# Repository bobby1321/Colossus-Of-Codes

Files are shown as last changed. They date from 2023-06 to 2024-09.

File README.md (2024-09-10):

# Colossus of Codes QMK Keyboard
This keyboard is a custom QMK-enabled board with a few unique features:
- Left-hand numpad
- Extra row of remappable function keys (F13-F24 by default)
- Rotary Encoder (Volume control by default)
- IO Expander chips to allow for 121 keys with a single RP2040!

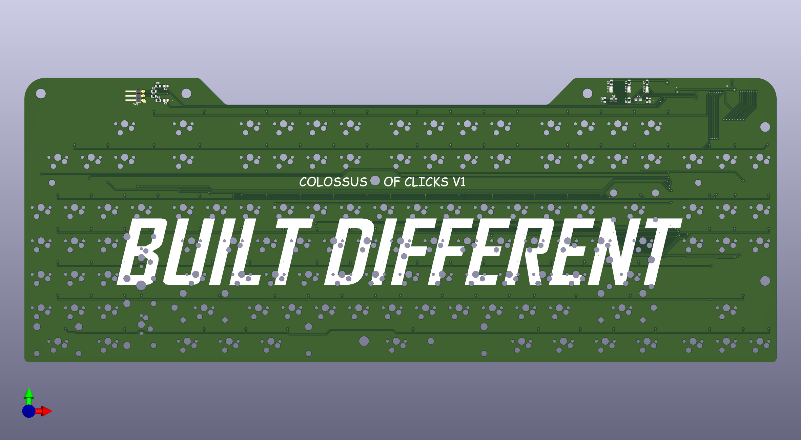
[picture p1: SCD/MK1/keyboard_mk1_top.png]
position


This design still needs some work (hence the V2 TODO list), but it is functional, and I've been using it as my daily driver for a few months now (as of Sept '24).

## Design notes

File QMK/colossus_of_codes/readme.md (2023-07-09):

# colossus_of_codes

colossus_of_codes

*A short description of the keyboard/project*

* Keyboard Maintainer: [bobby1321](https://github.com/bobby1321)
* Hardware Supported: *The PCBs, controllers supported*
* Hardware Availability: *Links to where you can find this hardware*

Make example for this keyboard (after setting up your build environment):

    make colossus_of_codes:default

Flashing example for this keyboard:

    make colossus_of_codes:default:flash

See the [build environment setup](https://docs.qmk.fm/#/getting_started_build_tools) and the [make instructions](https://docs.qmk.fm/#/getting_started_make_guide) for more information. Brand new to QMK? Start with our [Complete Newbs Guide](https://docs.qmk.fm/#/newbs).

## Bootloader

Enter the bootloader in 3 ways:

* **Bootmagic reset**: Hold down the key at (0,0) in the matrix (usually the top left key or Escape) and plug in the keyboard
* **Physical reset button**: Briefly press the button on the back of the PCB - some may have pads you must short instead
* **Keycode in layout**: Press the key mapped to `QK_BOOT` if it is available

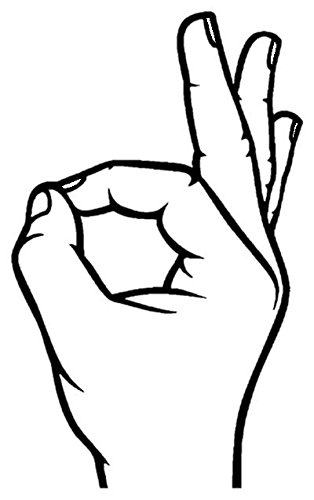
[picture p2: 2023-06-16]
Images/41HmWfeYpDL.jpg

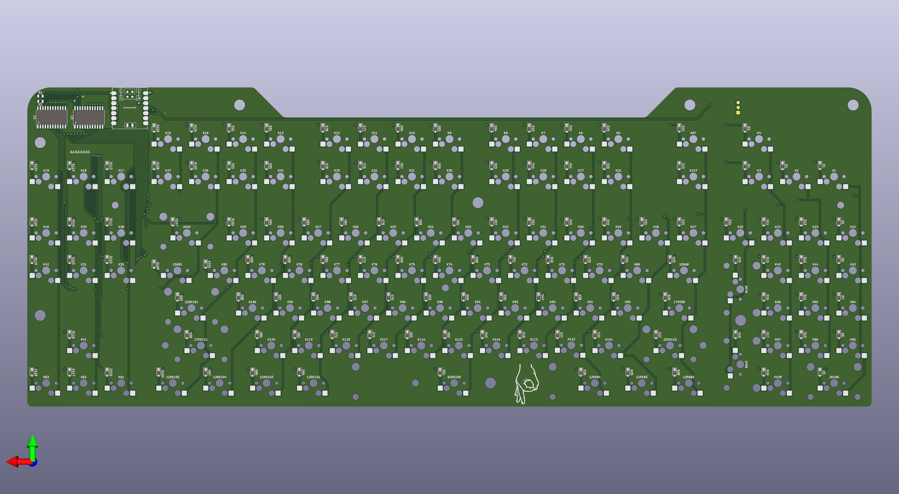
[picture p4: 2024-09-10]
SCD/MK1/keyboard_mk1_bottom.png

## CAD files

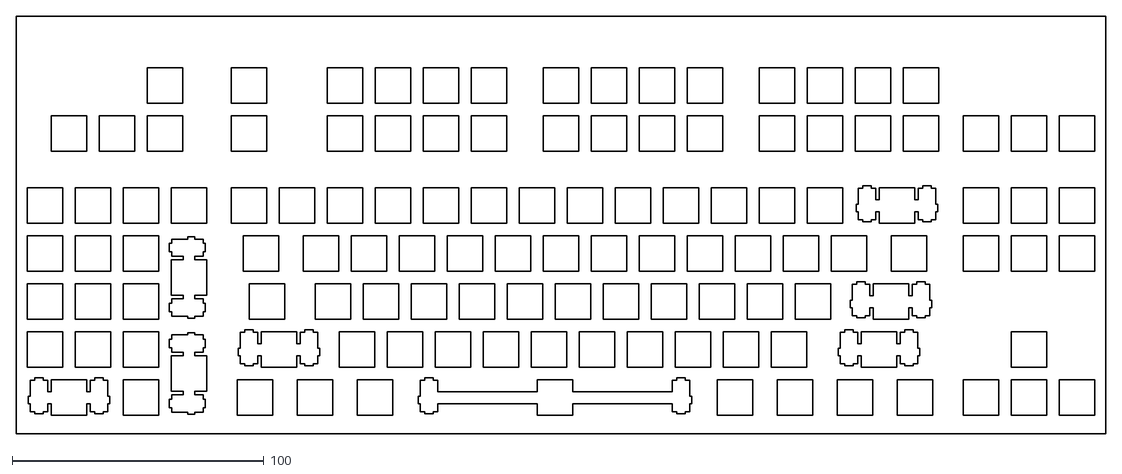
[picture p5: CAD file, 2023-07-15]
CAD/b24a91eeafafb1037e10217dc15ee6c39c0a37f9_switch.dxf
432.5 x 165.6

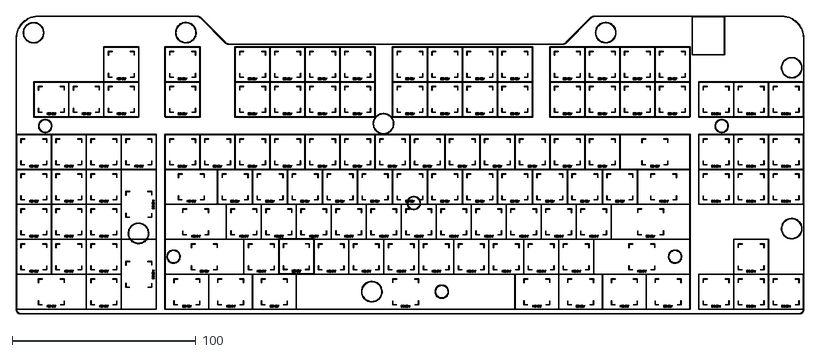
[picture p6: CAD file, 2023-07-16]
SCD/MK1/Gerbers/keyboard_mk1-User_Drawings.dxf
428.8 x 162.0

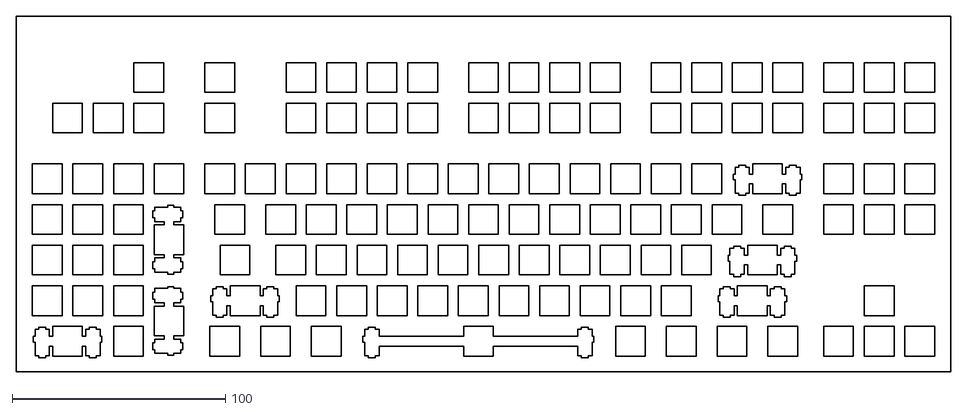
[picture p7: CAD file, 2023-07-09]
top_plate_drawing.dxf
438.6 x 166.9

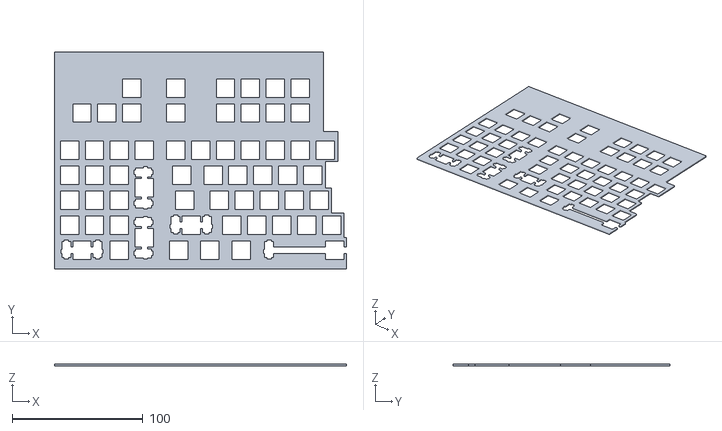
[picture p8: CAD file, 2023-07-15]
CAD/top_plate_left.stl
222.9 x 165.6 x 1.50

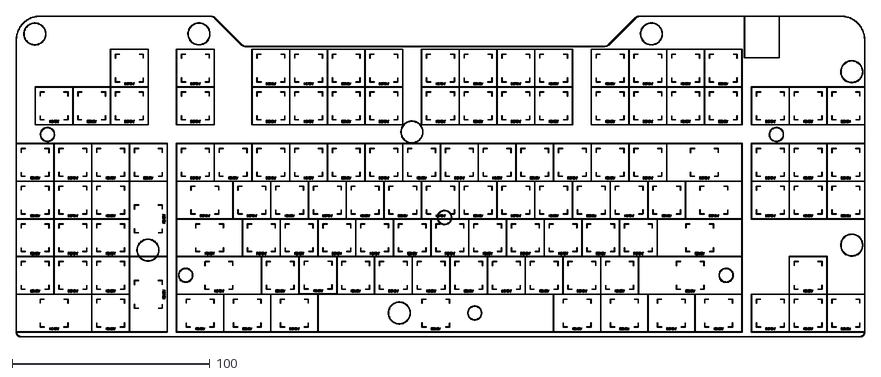
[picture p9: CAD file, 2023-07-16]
SCD/MK1/Gerbers/keyboard_mk1-User_Comments.dxf
428.8 x 162.0

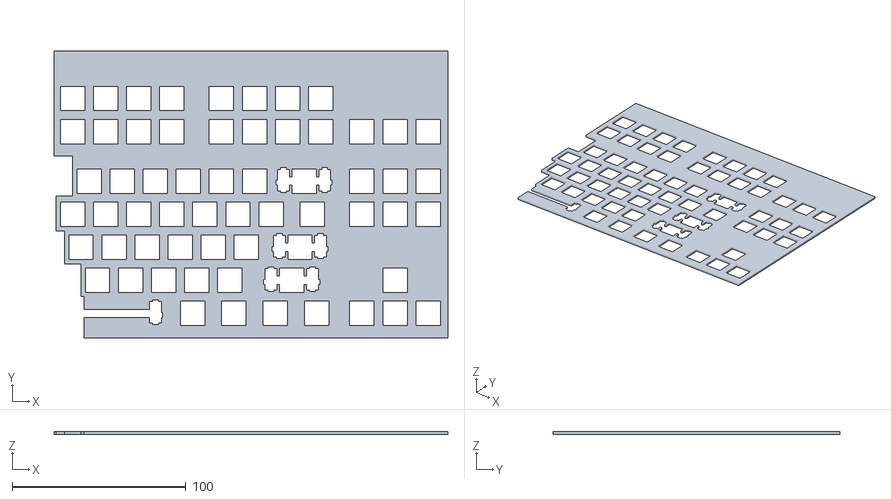
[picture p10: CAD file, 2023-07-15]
CAD/top_plate_right.stl
227.0 x 165.6 x 1.50

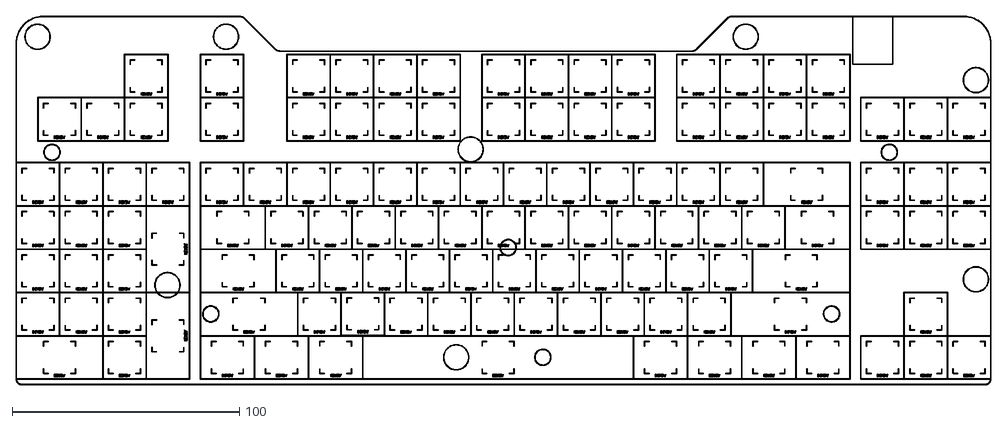
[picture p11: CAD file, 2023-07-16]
SCD/MK1/Gerbers/keyboard_mk1-Edge_Cuts.dxf
428.8 x 162.0

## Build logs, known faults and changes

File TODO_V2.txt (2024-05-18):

Things to do in V2:
	- Try to reduce dead area on board (talking about you top left corner)
	- Bigger resistors on LEDs (they are too bright)
	- Silkscreen things
	- Maybe design the case before / at the same time as the board so holes don't end up under keys :)
	- Also just put more holes in general
	- Try to put the chips on the front?
	- Maybe get chips with pull-down inputs, or just add pull-down resistors since I already have extra chips...
	- MEGA GAM3R RGB (per key, or just backlight?)
	- Thermal relief thingys? Make them better so that it doens't suck soldering to the ground plane.
	- Make the top 2 rows angled cause that would be cool
	- Toggle switches?
	- OLED screen...? maybe that's excessive...
	- Layer indicator LEDs
	- Increase kerf (that's a thing, right?) on top plate DXF
	- Also apparently construction lines get transfered to DXFs :)
	- Move function keys/esc closer to the number row
	- Move lock lights so that they are actually visible
	- Figure out how to support the volume roller better
	- Use thinner stainless steel
	- Print bottom plates stronger

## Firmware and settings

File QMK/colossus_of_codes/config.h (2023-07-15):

// Copyright 2023 bobby1321 (@bobby1321)
// SPDX-License-Identifier: GPL-2.0-or-later

#pragma once

/*
 * Feature disable options
 *  These options are also useful to firmware size reduction.
 */

/* disable debug print */
//#define NO_DEBUG

/* disable print */
//#define NO_PRINT

/* disable action features */
//#define NO_ACTION_LAYER
//#define NO_ACTION_TAPPING
//#define NO_ACTION_ONESHOT

#define I2C_DRIVER I2CD1
#define I2C1_SDA_PIN GP6
#define I2C1_SCL_PIN GP7

#define MATRIX_ROWS 7
#define MATRIX_COLS 22

#define ENCODERS_PAD_A { GP3 } // these are reveresed to reverse the direction of the encoder
#define ENCODERS_PAD_B { GP4 }

#define ENCODER_RESOLUTION 2

//#define DEBUG_MATRIX_SCAN_RATE

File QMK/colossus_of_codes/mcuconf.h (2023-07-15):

/*
    ChibiOS - Copyright (C) 2006..2021 Giovanni Di Sirio

    Licensed under the Apache License, Version 2.0 (the "License");
    you may not use this file except in compliance with the License.
    You may obtain a copy of the License at

        http://www.apache.org/licenses/LICENSE-2.0

    Unless required by applicable law or agreed to in writing, software
    distributed under the License is distributed on an "AS IS" BASIS,
    WITHOUT WARRANTIES OR CONDITIONS OF ANY KIND, either express or implied.
    See the License for the specific language governing permissions and
    limitations under the License.
*/

#ifndef MCUCONF_H
#define MCUCONF_H

/*
 * RP2040_MCUCONF drivers configuration.
 *
 * IRQ priorities:
 * 3...0        Lowest...Highest.
 *
 * DMA priorities:
 * 0...1        Lowest...Highest.
 */

#define RP2040_MCUCONF

/*
 * HAL driver system settings.
 */
#define RP_NO_INIT                          FALSE
#define RP_CORE1_START                      FALSE
#define RP_CORE1_VECTORS_TABLE              _vectors
#define RP_CORE1_ENTRY_POINT                _crt0_c1_entry
#define RP_CORE1_STACK_END                  __c1_main_stack_end__

/*
 * IRQ system settings.
 */
#define RP_IRQ_SYSTICK_PRIORITY             2
#define RP_IRQ_TIMER_ALARM0_PRIORITY        2
#define RP_IRQ_TIMER_ALARM1_PRIORITY        2
#define RP_IRQ_TIMER_ALARM2_PRIORITY        2
#define RP_IRQ_TIMER_ALARM3_PRIORITY        2
#define RP_IRQ_ADC1_PRIORITY                3
#define RP_IRQ_UART0_PRIORITY               3
#define RP_IRQ_UART1_PRIORITY               3
#define RP_IRQ_SPI0_PRIORITY                2
#define RP_IRQ_SPI1_PRIORITY                2
#define RP_IRQ_USB0_PRIORITY                3
#define RP_IRQ_I2C0_PRIORITY                2
#define RP_IRQ_I2C1_PRIORITY                1

/*
 * ADC driver system settings.
 */
#define RP_ADC_USE_ADC1                     TRUE

/*
 * SIO driver system settings.
 */
#define RP_SIO_USE_UART0                    TRUE
#define RP_SIO_USE_UART1                    FALSE

/*
 * SPI driver system settings.
 */
#define RP_SPI_USE_SPI0                     TRUE
#define RP_SPI_USE_SPI1                     FALSE
#define RP_SPI_SPI0_RX_DMA_CHANNEL          RP_DMA_CHANNEL_ID_ANY
#define RP_SPI_SPI0_TX_DMA_CHANNEL          RP_DMA_CHANNEL_ID_ANY
#define RP_SPI_SPI1_RX_DMA_CHANNEL          RP_DMA_CHANNEL_ID_ANY
#define RP_SPI_SPI1_TX_DMA_CHANNEL          RP_DMA_CHANNEL_ID_ANY
#define RP_SPI_SPI0_DMA_PRIORITY            1
#define RP_SPI_SPI1_DMA_PRIORITY            1
#define RP_SPI_DMA_ERROR_HOOK(spip)

/*
 * PWM driver system settings.
 */
#define RP_PWM_USE_PWM0                     FALSE
#define RP_PWM_USE_PWM1                     FALSE
#define RP_PWM_USE_PWM2                     FALSE
#define RP_PWM_USE_PWM3                     FALSE
#define RP_PWM_USE_PWM4                     FALSE
#define RP_PWM_USE_PWM5                     FALSE
#define RP_PWM_USE_PWM6                     FALSE
#define RP_PWM_USE_PWM7                     FALSE
#define RP_PWM_IRQ_WRAP_NUMBER_PRIORITY     3

/*
 * I2C driver system settings.
 */
#define RP_I2C_USE_I2C0                     FALSE
#define RP_I2C_USE_I2C1                     TRUE
#define RP_I2C_BUSY_TIMEOUT                 50
#define RP_I2C_ADDRESS_MODE_10BIT           FALSE

/*
 * USB driver system settings.
 */
#define RP_USB_USE_USBD0                    TRUE
#define RP_USB_FORCE_VBUS_DETECT            TRUE
#define RP_USE_EXTERNAL_VBUS_DETECT         FALSE
#define RP_USB_USE_SOF_INTR                 TRUE
#define RP_USB_USE_ERROR_DATA_SEQ_INTR      FALSE

#endif /* MCUCONF_H */

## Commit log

2023-06-16 Flipped stabilizer direction and added some silkscreen
    [keyboard_mk1.kicad_sch]
2023-06-21 Added debouncing and LED driving as well as a good name
    [keyboard_mk1.kicad_sch]
2023-06-23 Final check and remake gerbers for ordering first boards
    [keyboard_mk1-B_Cu.gbl, keyboard_mk1-B_Mask.gbs, keyboard_mk1-B_Paste.gbp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]
2023-06-24 Added dxf of top plate and some more silkscreen art
    [6ac5bc506e88c4a2174f2b779b30e21cccdd0afc_switch.dxf, keyboard_mk1-B_Adhesive.dxf, keyboard_mk1-Edge_Cuts.dxf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]
2023-06-26 Added cutout along top of board for potential expansion
2023-07-09 I think these are the production PCB files (not sure though)
    [6ac5bc506e88c4a2174f2b779b30e21cccdd0afc_switch.dxf, keyboard_mk1-B_Adhesive.dxf, keyboard_mk1-Edge_Cuts.dxf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]
2023-07-11 The I2C problem was a 0 that should have been a 1
    Now there's a new problem though...
    [colossus_of_codes.c, config.h, matrix.c]
2023-07-12 Stupid mistakes and pull up pins: a murder mystery
    Had to add pulldown resistors to the rows because the PCA9555 is only pull up. Also 0 & anything is always 0.
    [colossus_of_codes.c, config.h, keymap.c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]
2023-07-15 Finally working at a basic level at least. Encoder next.
2023-07-15 Added encoder (surprisingly easy)
2023-07-15 Updated top plate CADs
    [b24a91eeafafb1037e10217dc15ee6c39c0a37f9_switch.dxf, top_plate_left.stl, top_plate_right.stl]
2023-07-16 Updating top plate design
    [keyboard_mk1-Edge_Cuts.dxf, keyboard_mk1-User_Comments.dxf, keyboard_mk1-User_Drawings.dxf]
2024-09-10 Added a readme and PCB pics
